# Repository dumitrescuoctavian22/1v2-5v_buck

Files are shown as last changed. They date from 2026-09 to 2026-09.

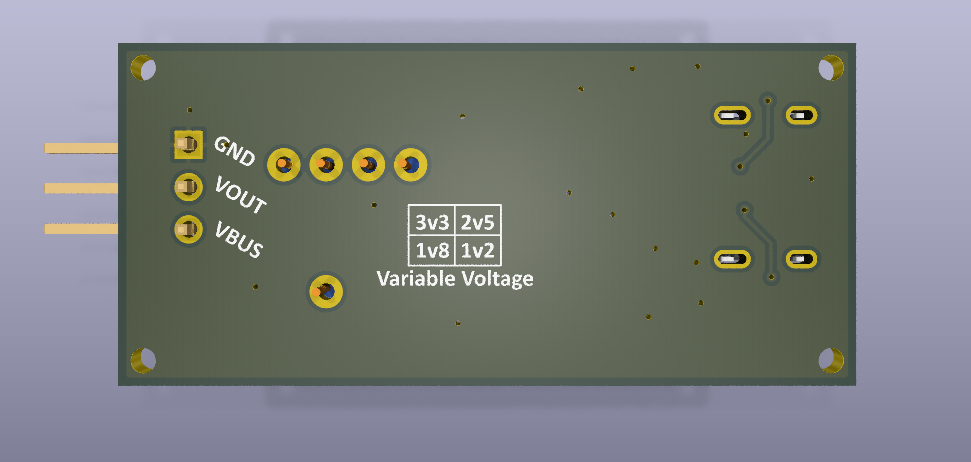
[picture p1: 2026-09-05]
images/3d model/back.PNG

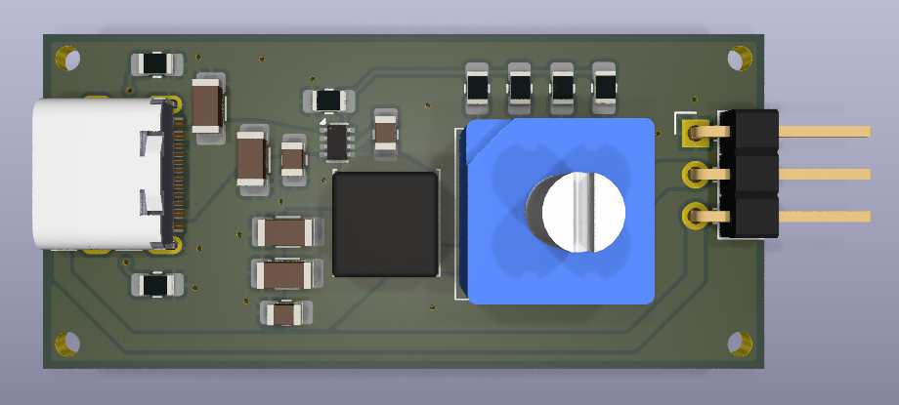
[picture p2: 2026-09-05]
images/3d model/front.PNG

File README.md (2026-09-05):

# USB-C ADJUSTABLE BUCK CONVERTER

## DESCRIPTION

A compact USB-C powered synchronous buck converter designed to provide a fixed 5 V rail and a selectable regulated output.

The project focuses on practical power electronics design, DC/DC converter selection, feedback network design, USB-C power input, PCB layout, high-current routing, mechanical design, and custom KiCad library development.

## FEATURES

* USB-C 5 V power input
* Up to 3 A continuous output capability
* Synchronous buck converter
* Selectable regulated output:

  * 1.2 V
  * 1.8 V
  * 2.5 V
  * 3.3 V
* Fixed 5 V output
* 3-pin output connector: 5 V / VOUT / GND
* Rotary switch for output voltage selection
* Input and output filtering
* 2-layer PCB
* 4 PCB mounting holes
* Custom rotary-switch footprint
* Custom rotary-switch 3D model
* Wide power traces
* Large ground plane
* USB-C power-only sink
* No USB Power Delivery required

## MAIN SPECIFICATIONS

Input:
USB-C 5 V

Converter:
TI TPS62933P

Topology:
Synchronous buck

Maximum output current:
3 A

Adjustable output:
1.2 V / 1.8 V / 2.5 V / 3.3 V

Fixed output:
5 V

Feedback reference:
0.8 V

Switching frequency:
500 kHz typical with RT floating

Inductor:
TDK VLS6045EX-6R8M
6.8 uH

PCB:
2-layer FR-4
1 oz copper

Output connector:
3-pin, 2.54 mm

Mounting holes:
4x
2.0 mm outer diameter
1.5 mm hole diameter

## OUTPUT CONNECTOR

The board uses a 3-pin output connector.

Pin 1:
5 V

Pin 2:
VOUT - adjustable regulated output

Pin 3:
GND

The 5 V output is connected to the USB-C VBUS rail.

The VOUT pin provides the regulated output selected using the rotary switch.

## USB-C INPUT

The USB-C connector is configured as a 5 V power-only sink.

CC1:
5.1 kOhm pull-down to GND

CC2:
5.1 kOhm pull-down to GND

D+:
Not connected

D-:
Not connected

SBU1:
Not connected

SBU2:
Not connected

USB Power Delivery is not used.

## POWER CONVERTER

The main regulator is the TI TPS62933P.

Key characteristics:

* 3 A continuous output capability
* 3.8 V to 30 V input range
* 0.8 V to 22 V output range
* Integrated MOSFETs
* Internal loop compensation
* Pulse-frequency modulation at light loads
* Spread-spectrum operation
* Overcurrent protection
* Overvoltage protection
* Undervoltage protection
* Undervoltage lockout
* Thermal protection

The RT pin is left floating, giving a typical switching frequency of 500 kHz.

## FEEDBACK NETWORK

The output voltage is selected using a rotary switch connected to the feedback resistor network.

Bottom feedback resistor:

* RFBB = 10.2 kOhm

Rotary switch positions:

Position 1:
RFBT = 5.1 kOhm
VOUT = 1.2 V

Position 2:
RFBT = 12.7 kOhm
VOUT = 1.8 V

Position 3:
RFBT = 21.5 kOhm
VOUT = 2.5 V

Position 4:
RFBT = 31.6 kOhm
VOUT = 3.3 V

The feedback resistors use 1% tolerance.

## INPUT FILTERING

The input filtering consists of:

* 47 uF bulk capacitor
* 10 uF ceramic capacitor
* 100 nF ceramic capacitor

The capacitors are placed close to the converter input to reduce input impedance and minimize the high-frequency switching loop.

## OUTPUT FILTERING

The output filtering consists of:

* 2 x 22 uF ceramic capacitors
* 1 x 100 nF ceramic capacitor
* 6.8 uH power inductor

The output capacitors are positioned close to the power stage.

## INDUCTOR

Part:
TDK VLS6045EX-6R8M

Value:
6.8 uH

Package:
6 x 6 x 4.5 mm

## ROTARY SWITCH

The rotary switch is used to select the feedback resistor and therefore the regulated output voltage.

Component:
Nidec Copal S-2050

The switch only carries the feedback-network current and does not carry the main output current.

## CUSTOM FOOTPRINT AND 3D MODEL

A custom KiCad footprint was created for the rotary switch.

A custom 3D model was also created for the component.

The custom library work included:

* Measuring the physical component
* Creating the through-hole pad layout
* Creating the PCB footprint
* Defining pad and courtyard dimensions
* Creating the 3D model
* Aligning the 3D model with the footprint
* Verifying the component in KiCad's 3D viewer

This allows the actual rotary switch to be accurately represented in both the PCB layout and 3D view.

## PCB DESIGN

The PCB is a 2-layer FR-4 design with 1 oz copper.

Important layout considerations include:

* Input capacitors placed close to VIN
* Short switching-current paths
* Short SW connection
* Inductor positioned close to the converter
* Output capacitors positioned close to the inductor
* Feedback routing kept away from the switching node
* Large ground plane
* Wide VIN and VOUT traces
* Additional copper around the power components for thermal management

## CURRENT ROUTING

The main power paths use wide copper traces.

Important high-current paths include:

* USB-C VBUS to the input capacitors
* Input capacitors to the TPS62933P
* TPS62933P to the inductor
* Inductor to the output capacitors
* Output capacitors to the VOUT connector

Approximately 1.5 mm wide traces are used for the main power paths where appropriate.

## MOUNTING

The PCB includes four mounting holes.

Mounting-hole geometry:

* Outer diameter: 2.0 mm
* Hole diameter: 1.5 mm

The mounting holes provide mechanical mounting points for PCB standoffs or suitable hardware.

## DESIGN GOALS

The main goals of the project were to demonstrate practical experience with:

* DC/DC converter selection
* Synchronous buck converter design
* Feedback network design
* USB-C power input
* Power component selection
* Inductor selection
* Capacitor selection
* Switching power supply layout
* Ground-plane design
* Custom KiCad footprint creation
* Custom 3D model creation
* Mechanical PCB design

## TOOLS

* KiCad
* Schematic capture
* PCB layout
* PCB routing
* Custom footprint creation
* Custom 3D model creation

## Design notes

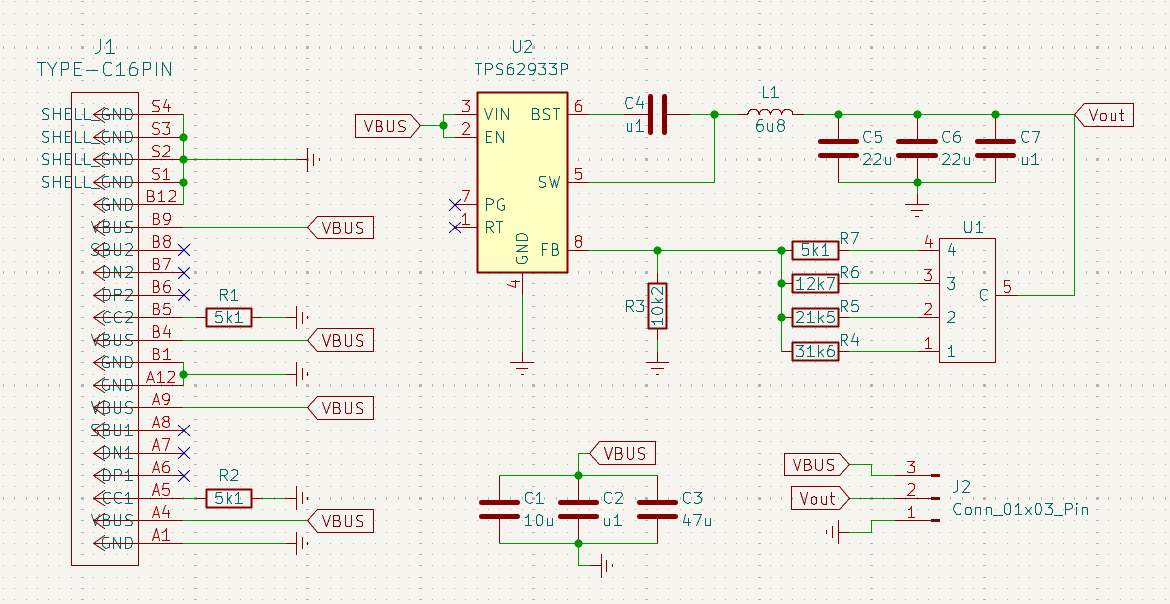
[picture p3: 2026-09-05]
images/schematic.PNG

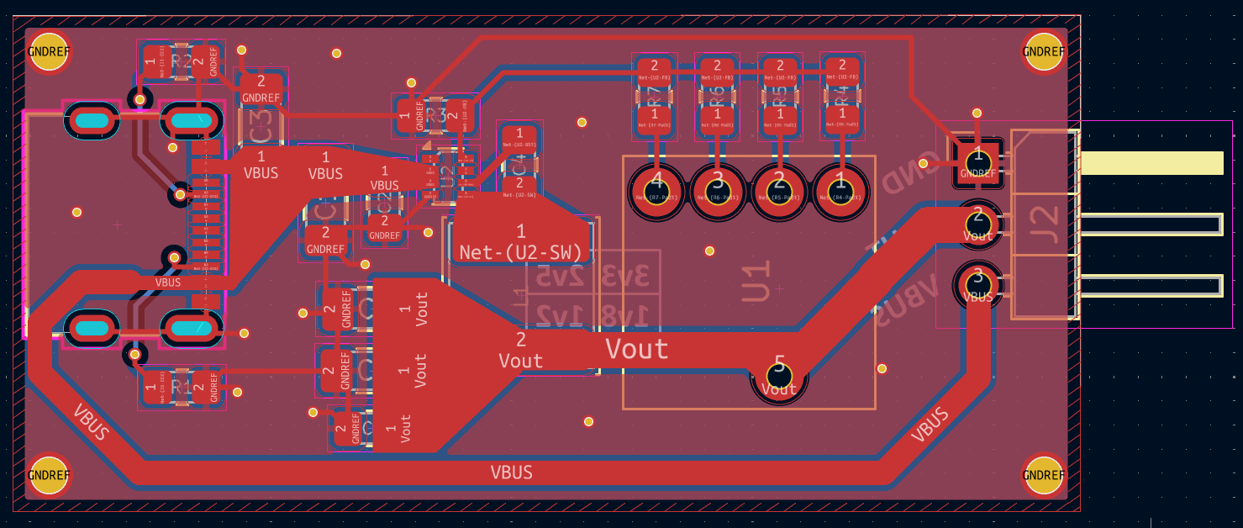
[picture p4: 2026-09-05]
images/pcb/pcbMain.PNG

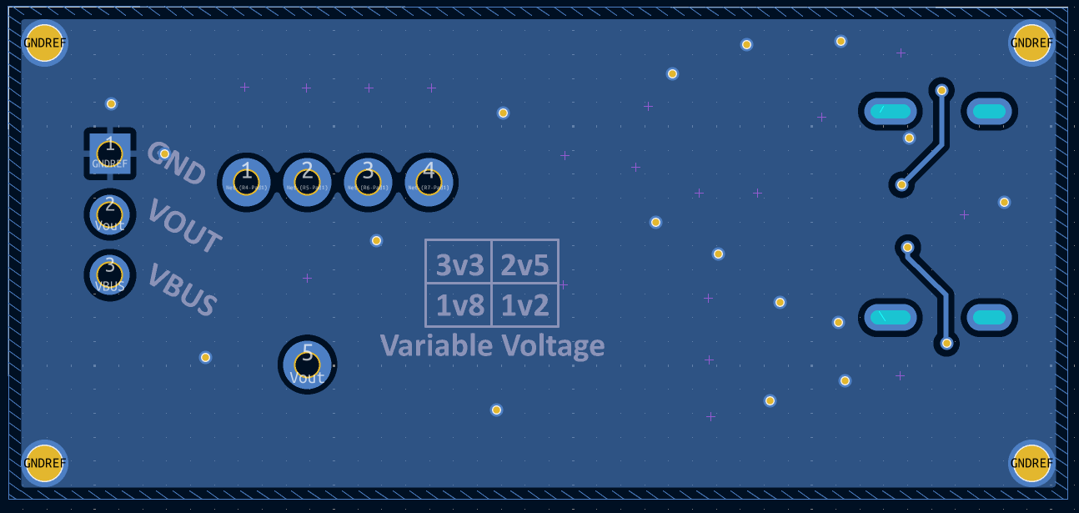
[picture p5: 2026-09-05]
images/pcb/back.PNG

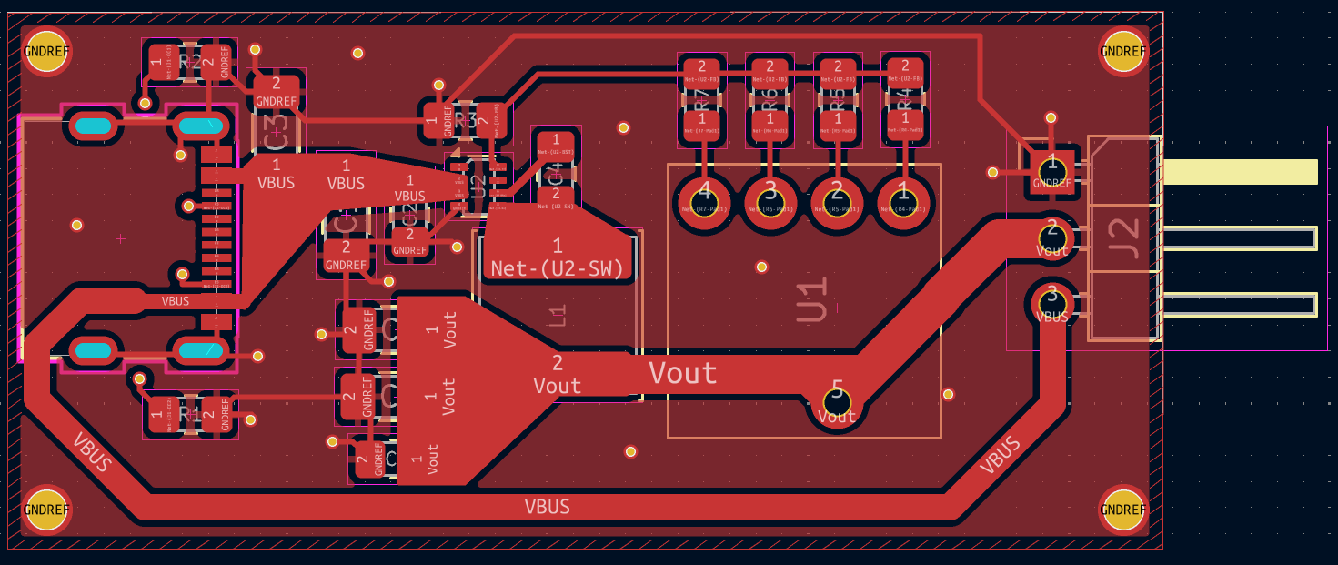
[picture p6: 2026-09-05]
images/pcb/front.PNG

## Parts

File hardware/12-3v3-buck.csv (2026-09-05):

Reference | Value | Footprint | Datasheet | Qty | DNP | Exclude from BOM | Exclude from Board
C1 | 10u | Capacitor_SMD:C_1206_3216Metric_Pad1.33x1.80mm_HandSolder | ~ | 1
C2,C4,C7 | u1 | Capacitor_SMD:C_0805_2012Metric_Pad1.18x1.45mm_HandSolder | ~ | 3
C3 | 47u | Capacitor_SMD:C_1206_3216Metric_Pad1.33x1.80mm_HandSolder | ~ | 1
C5,C6 | 22u | Capacitor_SMD:C_1206_3216Metric_Pad1.33x1.80mm_HandSolder | ~ | 2
J1 | TYPE-C16PIN | 1A:CONN16_C16PIN_SHN | TYPE-C16PIN | 1
J2 | Conn_01x03_Pin | Connector_PinHeader_2.54mm:PinHeader_1x03_P2.54mm_Horizontal | ~ | 1
L1 | 6u8 | Inductor_SMD:L_APV_ANR6045 | ~ | 1
R1,R2,R7 | 5k1 | Resistor_SMD:R_0805_2012Metric_Pad1.20x1.40mm_HandSolder | ~ | 3
R3 | 10k2 | Resistor_SMD:R_0805_2012Metric_Pad1.20x1.40mm_HandSolder | ~ | 1
R4 | 31k6 | Resistor_SMD:R_0805_2012Metric_Pad1.20x1.40mm_HandSolder | ~ | 1
R5 | 21k5 | Resistor_SMD:R_0805_2012Metric_Pad1.20x1.40mm_HandSolder | ~ | 1
R6 | 12k7 | Resistor_SMD:R_0805_2012Metric_Pad1.20x1.40mm_HandSolder | ~ | 1
U1 | ~ | 1A:SP4T Rotary Switch S-2051 |  | 1
U2 | TPS62933P | Package_TO_SOT_SMD:SOT-583-8 | https://www.ti.com/lit/ds/symlink/tps62933.pdf | 1

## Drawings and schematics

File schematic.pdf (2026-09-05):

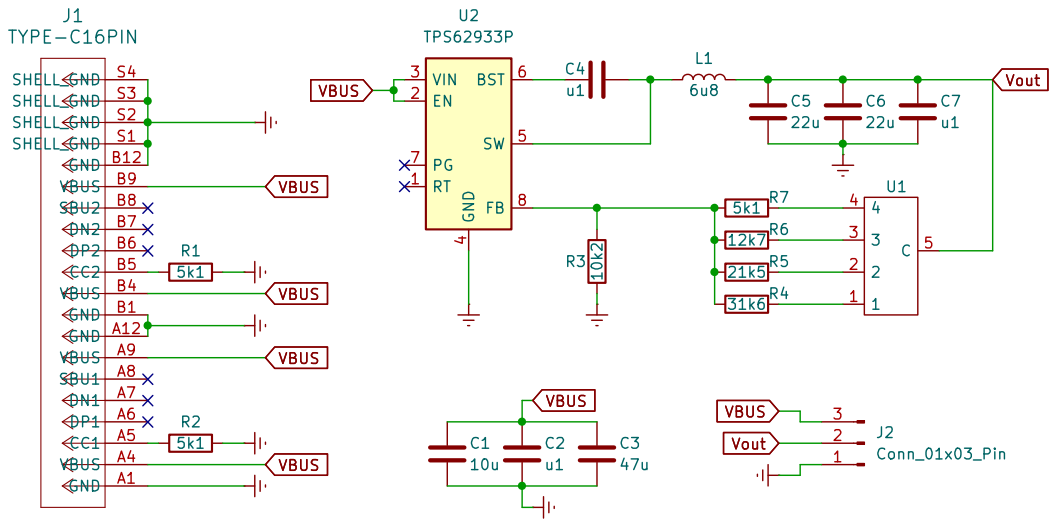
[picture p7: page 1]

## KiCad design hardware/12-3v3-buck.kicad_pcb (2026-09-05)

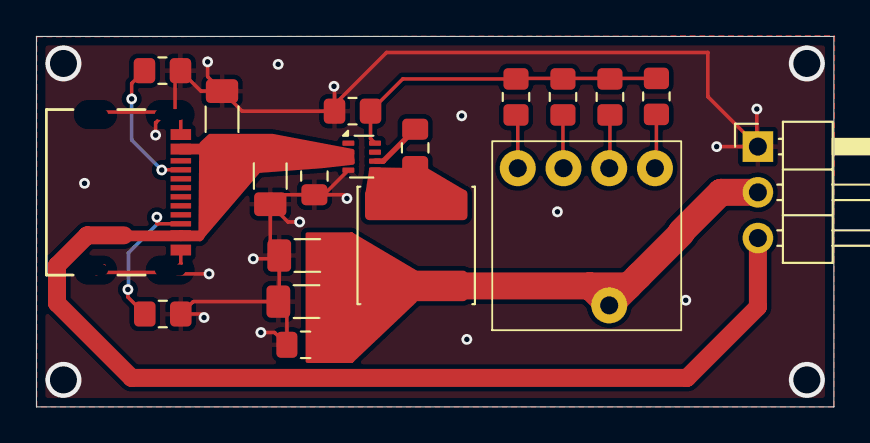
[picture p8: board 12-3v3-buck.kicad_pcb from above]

Board: 2 copper layers, 44.3 x 20.6 mm, 19 parts (0 on the bottom side), 12 nets.

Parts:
C1: 10u; C_1206_3216Metric_Pad1.33x1.80mm_HandSolder
C2, C4, C7: u1; C_0805_2012Metric_Pad1.18x1.45mm_HandSolder
C3: 47u; C_1206_3216Metric_Pad1.33x1.80mm_HandSolder
C5, C6: 22u; C_1206_3216Metric_Pad1.33x1.80mm_HandSolder
J1: TYPE-C16PIN; CONN16_C16PIN_SHN
J2: Conn_01x03_Pin; PinHeader_1x03_P2.54mm_Horizontal
L1: 6u8; L_APV_ANR6045
R1, R2, R7: 5k1; R_0805_2012Metric_Pad1.20x1.40mm_HandSolder
R3: 10k2; R_0805_2012Metric_Pad1.20x1.40mm_HandSolder
R4: 31k6; R_0805_2012Metric_Pad1.20x1.40mm_HandSolder
R5: 21k5; R_0805_2012Metric_Pad1.20x1.40mm_HandSolder
R6: 12k7; R_0805_2012Metric_Pad1.20x1.40mm_HandSolder
U1: SP4T Rotary Switch S-2051
U2: TPS62933P; SOT-583-8

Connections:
GNDREF: C1.2, C2.2, C3.2, C5.2, C6.2, C7.2, J1.A1 (GND), J1.A12 (GND), J1.B1 (GND), J1.B12 (GND), J2.1, R1.2, R2.2, R3.1, U2.4 (GND)
unnamed: J1.A5 (CC1), R2.1
unnamed: J1.B5 (CC2), R1.1
unnamed: R4.1, U1.1
unnamed: R5.1, U1.2
unnamed: R6.1, U1.3
unnamed: R7.1, U1.4
unnamed: C4.1, U2.6 (BST)
unnamed: R3.2, R4.2, R5.2, R6.2, R7.2, U2.8 (FB)
unnamed: C4.2, L1.1, U2.5 (SW)
VBUS: C1.1, C2.1, C3.1, J1.A4 (VBUS), J1.A9 (VBUS), J1.B4 (VBUS), J1.B9 (VBUS), J2.3, U2.2 (EN), U2.3 (VIN)
Vout: C5.1, C6.1, C7.1, J2.2, L1.2, U1.5 (C)
